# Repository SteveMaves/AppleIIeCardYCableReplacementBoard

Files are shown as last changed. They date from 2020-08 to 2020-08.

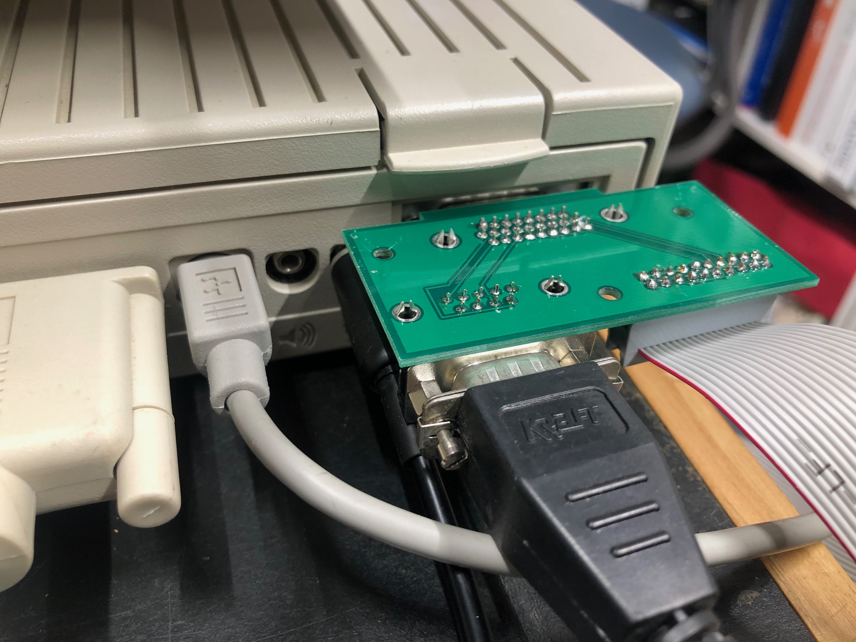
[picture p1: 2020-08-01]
Pictures/PluggedIntoLC.jpg

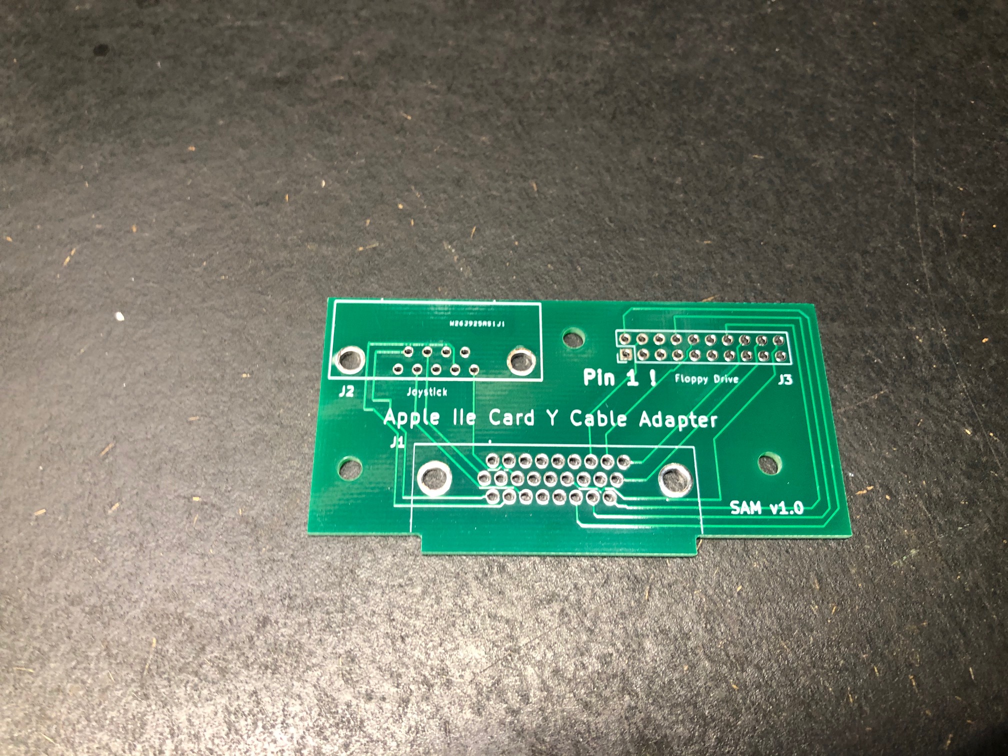
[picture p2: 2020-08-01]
Pictures/RawBoard.jpg

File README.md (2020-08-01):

# AppleIIeCardYCableReplacementBoard
This Circuit Board Design Allows FloppyEmu and a Joystick to be connected to an Apple IIe Card in a Macintosh

The purpose of this design is to replace the Apple IIe card spliter cable that is a part of the Apple IIe card 
that fit into some Macintosh computers in the early 90's.  The Y-Splitter cable is Apple Part Number 590-0703-A

Note that this circuit board only contains wiring for 5 volts.
It is suitable to run the FloppyEmu Floppy Drive Emulator device...
https://www.bigmessowires.com/floppy-emu/
but this circuit board will not power an authentic Apple drive which requires 12 volts.

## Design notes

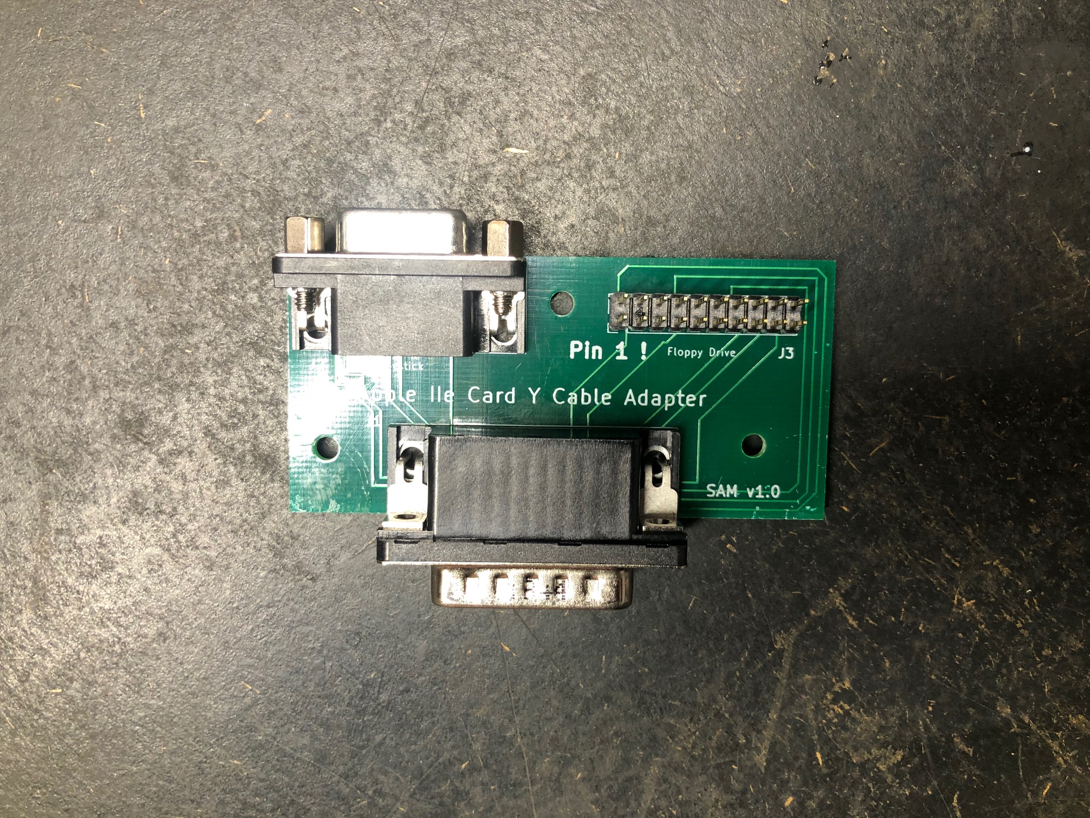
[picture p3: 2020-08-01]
Pictures/Populated Board.jpg

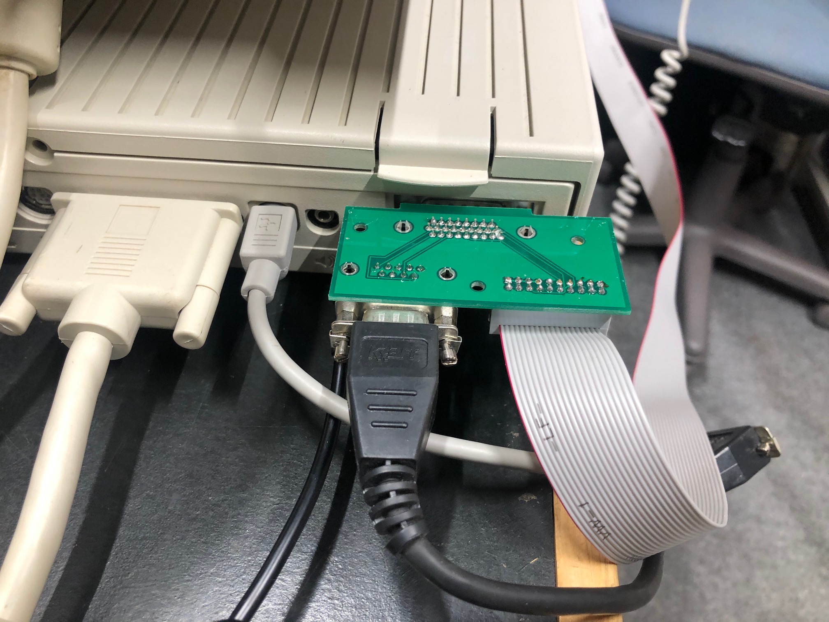
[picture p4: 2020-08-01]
Pictures/PluggedIntoLCTopView.jpg

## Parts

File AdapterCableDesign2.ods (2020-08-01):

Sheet: BOM
Bill of Materials – Apple Iie Card Y Cable Circuit Board
Qty | Board Ref. | Digikey Part No. | Amazon Link | Description | Purpose
1 | J1 | 609-4024-ND (https://www.digikey.com/product-detail/en/amphenol-icc-fci/10090926-P264XLF/609-4024-ND/2350309) |  | 26 Pin Connector | Apple Iie Card
1 | J2 | AE10921-ND (https://www.digikey.com/product-detail/en/assmann-wsw-components/A-DF-09-A-KG-T2S/AE10921-ND/1241800) |  | 9 Pin Connector | Joystick Port
1 | J3 |  | DIKAVS Pin Strip (https://www.amazon.com/DIKAVS-Break-Away-2x20-pin-Header-Raspberry/dp/B075VNBD3R?ref_=fsclp_pl_dp_1) | 2x 10 pin Header | FloppyEmu Port

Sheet: PInouts
Connector Design Apple Iie Card to FloppyEmu 20 Pin Header
 |  | Floppy Emu
 | Header | Signal | iie Card
 | 20 Pin | Name | 26 Pin
 | 1 | GND | 4 | View from back of computer (from behind connector)
 | 3 | GND | 4
 | 5 | GND | 13
 | 7 | GND | 14
 |  | n c | n c
 | 11 | +5 V | 5
 |  | n c
 |  | nc
 |  | nc | n c
 | 20 | PWM | 15
 | 2 | PHASE0 | 24 | Links Here:
 | 4 | PHASE1 | 7 | http://archive.retro.co.za/mirrors/68000/www.vintagemacworld.com/lc_card_faq.html
 | 6 | PHASE2 | 16 | https://www.bigmessowires.com/category/macintosh-floppy-emu/page/14/
 | 8 | PHASE3 | 25 | https://oldcrap.org/2018/08/24/apple-disk-5-25/
 | 10 | /WREQ | 8 | http://wiki.apple2.org/index.php?title=Pinouts#Apple_Game_Port_.289-pin_Connector.29
 | 12 | SELECT | 17
 | 14 | /ENABLE | 26
 | 16 | RD | 9
 | 18 | WR | 18
 | Joystick |  | Apple Iie
 | 9-pin |  | 26 Pin
 | 1 | PB 1 | 1
 | 2 | 5 v | 21
 | 3 | gnd | 2
 | 4 | pdl 2 | 20
 | 5 | pdl 0 | 12
 | 6 | PB 2 | 19
 | 7 | PB 0 | 10
 | 8 | pdl 1 | 3
 | 9 | pdl 3 | 11

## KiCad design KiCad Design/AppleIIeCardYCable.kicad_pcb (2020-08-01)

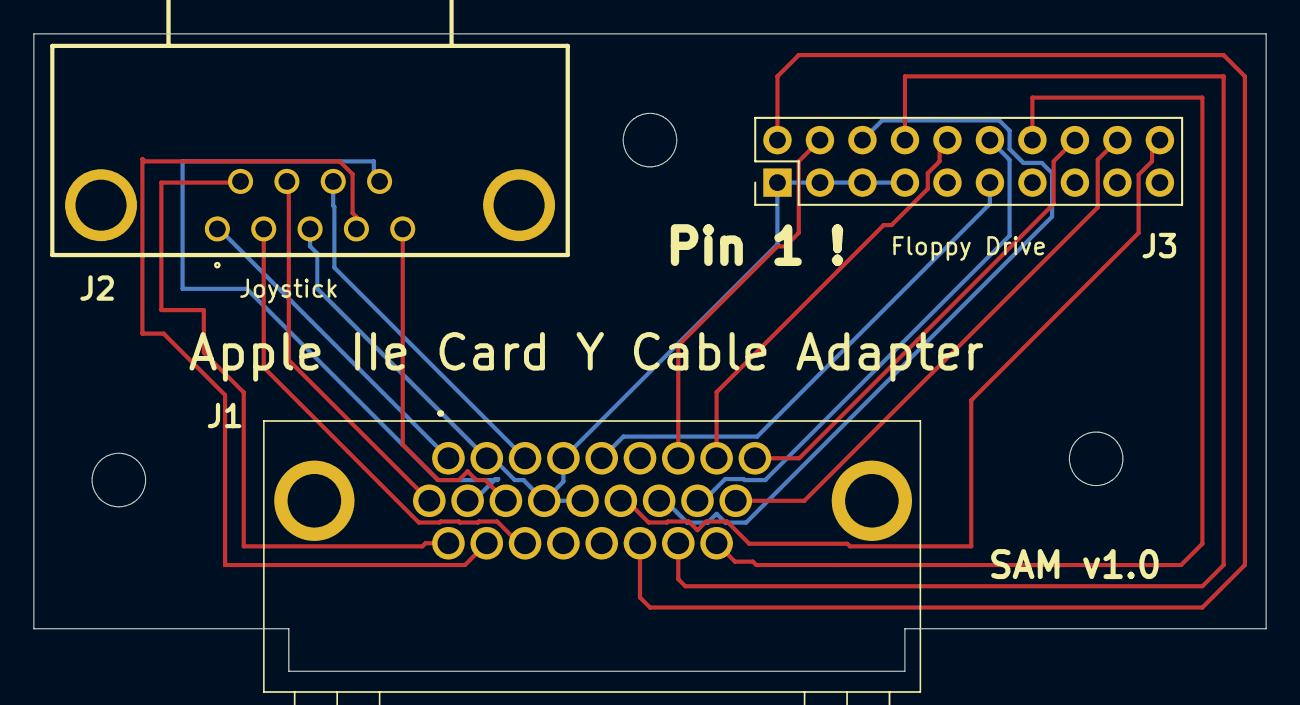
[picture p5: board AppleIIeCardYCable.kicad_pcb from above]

Board: 2 copper layers, 73.7 x 38.1 mm, 6 parts (0 on the bottom side), 20 nets.

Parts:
H1, H2, H3: MountingHole_3.2mm_M3
J1: 10090926-P264XLF; 10090926P264XLF
J2: A-DF_09_A_KG-T2S; A-DF-09-AKG-T2S_1
J3: Conn_02x10_Odd_Even; PinHeader_2x10_P2.54mm_Vertical

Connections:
+5V: J1.5, J3.11
GND: J1.2, J1.4, J1.13, J1.14, J2.3, J3.1, J3.3, J3.5, J3.7
unnamed: J1.1, J2.1
unnamed: J1.3, J2.8
unnamed: J1.7, J3.4
unnamed: J1.8, J3.10
unnamed: J1.9, J3.16
unnamed: J1.10, J2.7
unnamed: J1.11, J2.9
unnamed: J1.12, J2.5
unnamed: J1.15, J3.20
unnamed: J1.16, J3.6
unnamed: J1.17, J3.12
unnamed: J1.18, J3.18
unnamed: J1.19, J2.6
unnamed: J1.20, J2.4
unnamed: J1.21, J2.2
unnamed: J1.24, J3.2
unnamed: J1.25, J3.8
unnamed: J1.26, J3.14

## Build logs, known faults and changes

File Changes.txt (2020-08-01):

Copyright Steve Maves 2020.

This source describes Open Hardware and is licensed under the CERN-OHL-P
v2

You may redistribute and modify this documentation and make products
using it under the terms of the CERN-OHL-P v2 (https:/cern.ch/cern-ohl).
This documentation is distributed WITHOUT ANY EXPRESS OR IMPLIED
WARRANTY, INCLUDING OF MERCHANTABILITY, SATISFACTORY QUALITY
AND FITNESS FOR A PARTICULAR PURPOSE. Please see the CERN-OHL-P v2
for applicable conditions

Revision History

Verion 1.0	Initial Release
